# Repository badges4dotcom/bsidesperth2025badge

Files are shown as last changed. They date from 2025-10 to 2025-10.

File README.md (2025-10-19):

# BSides Perth 2025 Badge

## Physical Badge

Instructions on how to assemble the physical badge can be found [here](docs/AssemblyInstructions.md)

If a re-download of the physical badge is required, follow these [instructions](docs/DownloadInstructions.md). This will be required if you wish to attempt the online challenges (see Known Issues below).

### Parts List

| Qty | Item | Link | Alternative Link |
| --- | --- | --- | --- |
| 4	| 6x6x6mm Push Button Tactile Switch | [Link](https://a.aliexpress.com/_mtKEuoZ) || 
| 4	| 10k 1/4W 1% Metal Film Resistor | [Link](https://a.aliexpress.com/_m0tmaNF) ||
| 1	| 1x4 2.54mm Male Header Pin Connector | [Link](https://a.aliexpress.com/_mLn1ap7) ||
| 1	| 1x8 2.54mm Female Header Pin Connector | [Link](https://a.aliexpress.com/_mquvebf) | [Link](https://a.aliexpress.com/_mNltGYh) |
| 1	| 1x4 2.54mm Female Header Pin Connector | [Link](https://a.aliexpress.com/_mquvebf) | [Link](https://a.aliexpress.com/_mNltGYh) |
| 2	| 1x15 2.54mm Female Header Pin Connector | [Link](https://a.aliexpress.com/_mquvebf) | [Link](https://a.aliexpress.com/_mNltGYh) |
| 1	| 2x3 2.54mm Femal Header Pin Connector	| [Link](https://a.aliexpress.com/_mK6bxvJ) ||
| 1	| ESP32 DOIT DevKit v1 - 30Pin | [Link](https://a.aliexpress.com/_mr7LSPJ) ||
| 1	| 1.8" LCD TFT Display | [Link](https://a.aliexpress.com/_mPspKyp) ||

## Virtual Badge

The virtual badge can be accessed here: https://badge.bsidesperth.com.au/

The code for the Virtual Badge code can be found in this repository under "VirtualBadge".

The virtual badge does not support "Online Challenges", but does contain hidden features such as a second episode, cheats, and an easter egg.

The virtual badge now supports keyboard inputs. The four buttons are mapped to W [Up], S [Down], A [Left/A], and D [Right/B]. Once a keyboard input is used, the symbols used in the sequence game change to U = UP, D = DOWN, L = LEFT, R = RIGHT. Thanks again to Matt for the suggestion and the code snippet for this feature. 

## Physical Badge Code Template

There is a basic template for an Arduino program under the folder "Template". The template demonstrates basic use of the LCD screen, ESP32, and button inputs. The download instructions can be found [here](docs/DownloadInstructions.md).

## Virtual Badge Server (API for Online Challenges)

Code for the Virtual Badge Server (API for Online Challenges) will be made available ~1st November 2025.

## Badge Holder (3D Print)

A badge holder can be 3D printed using an off-the-shelf 3D printer. Recommended print settings are PLA plastic, 60+% infill, 40mm/s print speed. Some stringing may occur if filament is damp and/or print speed is too high.

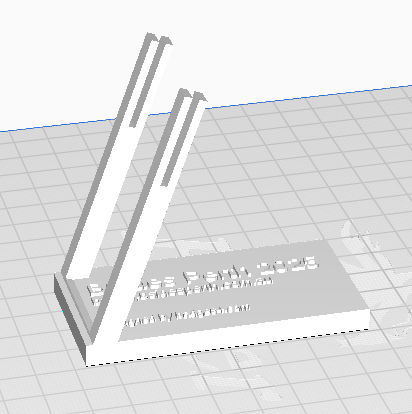
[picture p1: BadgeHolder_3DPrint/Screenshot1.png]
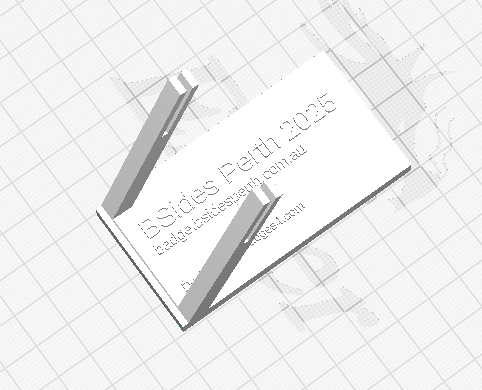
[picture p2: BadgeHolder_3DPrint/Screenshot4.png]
 

## Customisation

Customisation of the virtual and physical badge are both possible. Extra details can be found [here](docs/Customisation.md)

## Known Issues

- To play the Online Challenges on a ESP32 supplied in a component pack, a re-download of the physical badge code to the ESP32 is required. [Fixed]
- Online Challenges were unavailable (18th Oct) due to firewall issue. This has since been resolved. [Fixed]
- Offline Challenges now generates sequences which use all four buttons (only three buttons were being used in the original code). [Fixed]

## Like the game/badge?

"Buy Me A Coffee" (https://buymeacoffee.com/badges4dotcom)

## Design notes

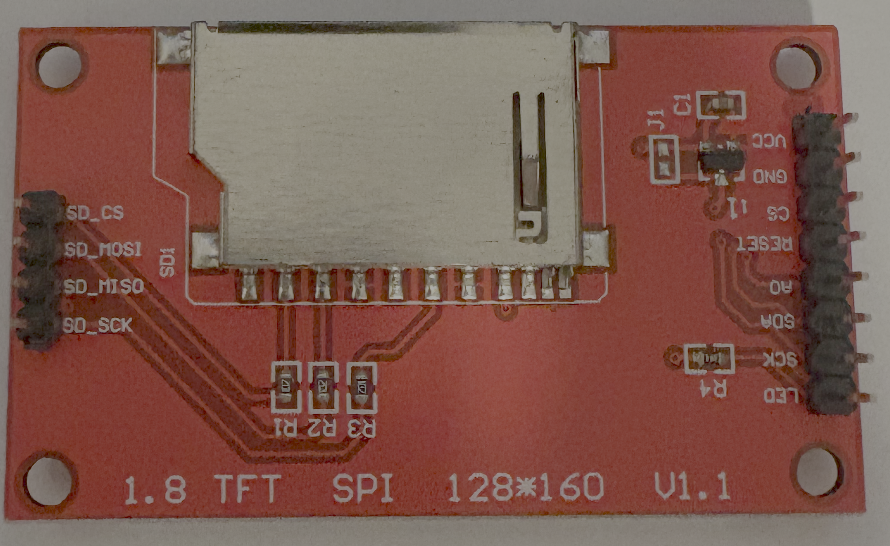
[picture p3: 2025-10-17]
docs/Images/LCD.png

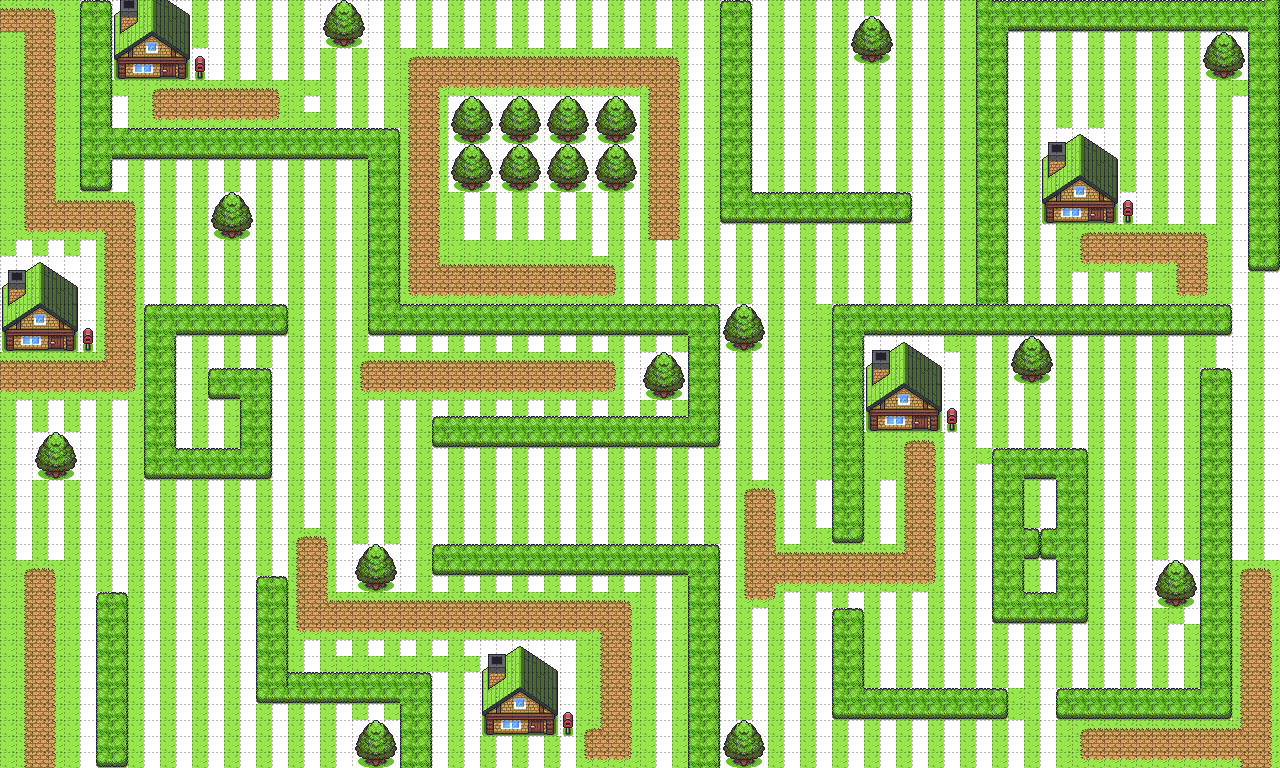
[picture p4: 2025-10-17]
GameMap/Exports/Episode1Map.png

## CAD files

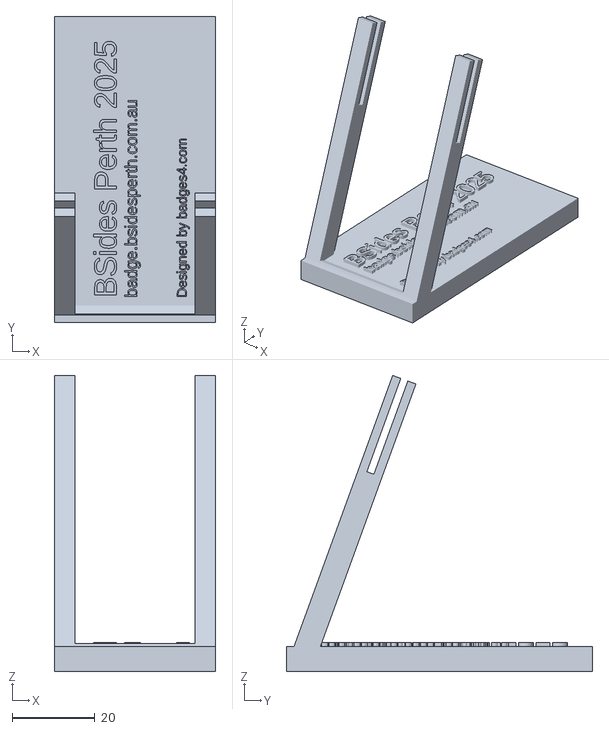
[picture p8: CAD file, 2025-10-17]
BadgeHolder_3DPrint/BadgeHolder.stl
39.0 x 74.0 x 71.6

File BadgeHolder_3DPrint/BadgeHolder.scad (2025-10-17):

union() {
    translate([0, 6, 0]) rotate([70,0,0]) {
        difference() {
            union() {
                cube([5, 74, 6]);
                cube([39, 5, 6]);
                translate([34, 0, 0]) cube([5, 74, 6]);
            }
            translate([-1,50,2.1]) cube([41, 25, 1.8]);
        }
    }
    cube([39, 74, 6]);
}

translate([15, 6, 6]) rotate([0, 0, 90]) linear_extrude(1) text("BSides Perth 2025", 5.5);
translate([20, 6, 6]) rotate([0, 0, 90]) linear_extrude(1) text("badge.bsidesperth.com.au", 3);
translate([32, 6, 6]) rotate([0, 0, 90]) linear_extrude(1) text("Designed by badges4.com", 2.4);

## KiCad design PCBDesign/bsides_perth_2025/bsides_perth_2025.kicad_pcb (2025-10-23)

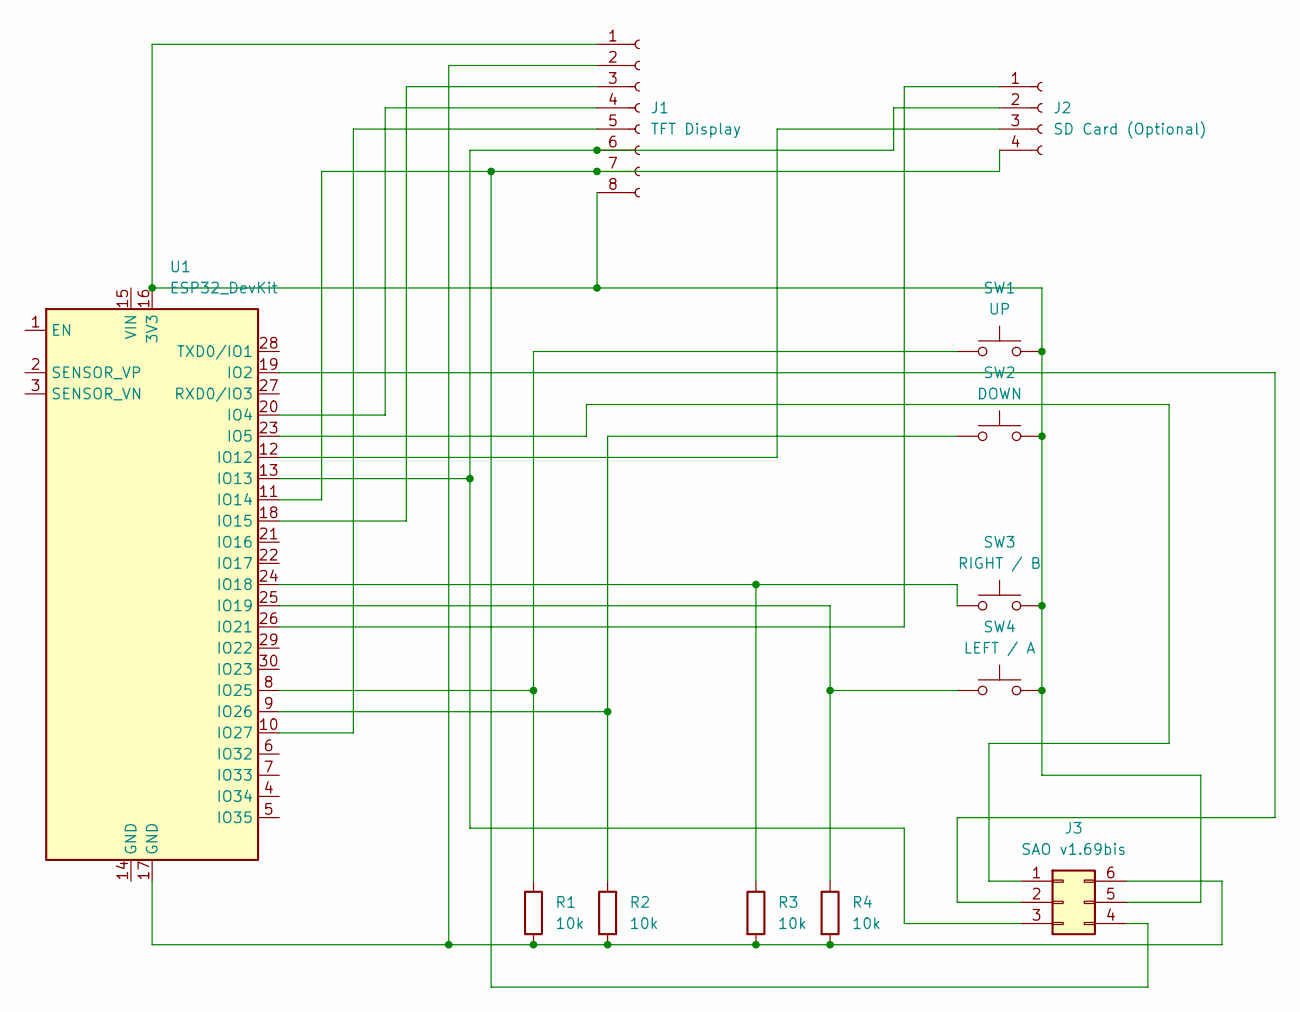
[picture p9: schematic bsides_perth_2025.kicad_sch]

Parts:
J1: TFT Display; PinHeader_1x08_P2.54mm_Vertical
J2: SD Card (Optional); PinHeader_1x04_P2.54mm_Vertical
J3: SAO v1.69bis; PinHeader_2x03_P2.54mm_Vertical
R1, R2, R3, R4: 10k; R_Axial_DIN0207_L6.3mm_D2.5mm_P10.16mm_Horizontal
SW1: UP; SW_PUSH_6mm_H5mm
SW2: DOWN; SW_PUSH_6mm_H5mm
SW3: RIGHT / B; SW_PUSH_6mm_H5mm
SW4: LEFT / A; SW_PUSH_6mm_H5mm
U1: ESP32_DevKit; esp32_devkit_v1_doit

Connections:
unnamed: J1.1, J1.8, J3.5, SW1.2, SW2.2, SW3.2, SW4.2, U1.16 (3V3)
unnamed: J1.2, J3.6, R1.2, R2.2, R3.2, R4.2, U1.17 (GND)
unnamed: J1.3, U1.18 (IO15)
unnamed: J1.4, U1.20 (IO4)
unnamed: J1.5, U1.10 (IO27)
unnamed: J1.6, J2.2, J3.3, U1.13 (IO13)
unnamed: J1.7, J2.4, J3.4, U1.11 (IO14)
unnamed: J2.1, U1.26 (IO21)
unnamed: J2.3, U1.12 (IO12)
unnamed: J3.1, U1.23 (IO5)
unnamed: J3.2, U1.19 (IO2)
unnamed: R1.1, SW1.1, U1.8 (IO25)
unnamed: R2.1, SW2.1, U1.9 (IO26)
unnamed: R3.1, SW3.1, U1.24 (IO18)
unnamed: R4.1, SW4.1, U1.25 (IO19)

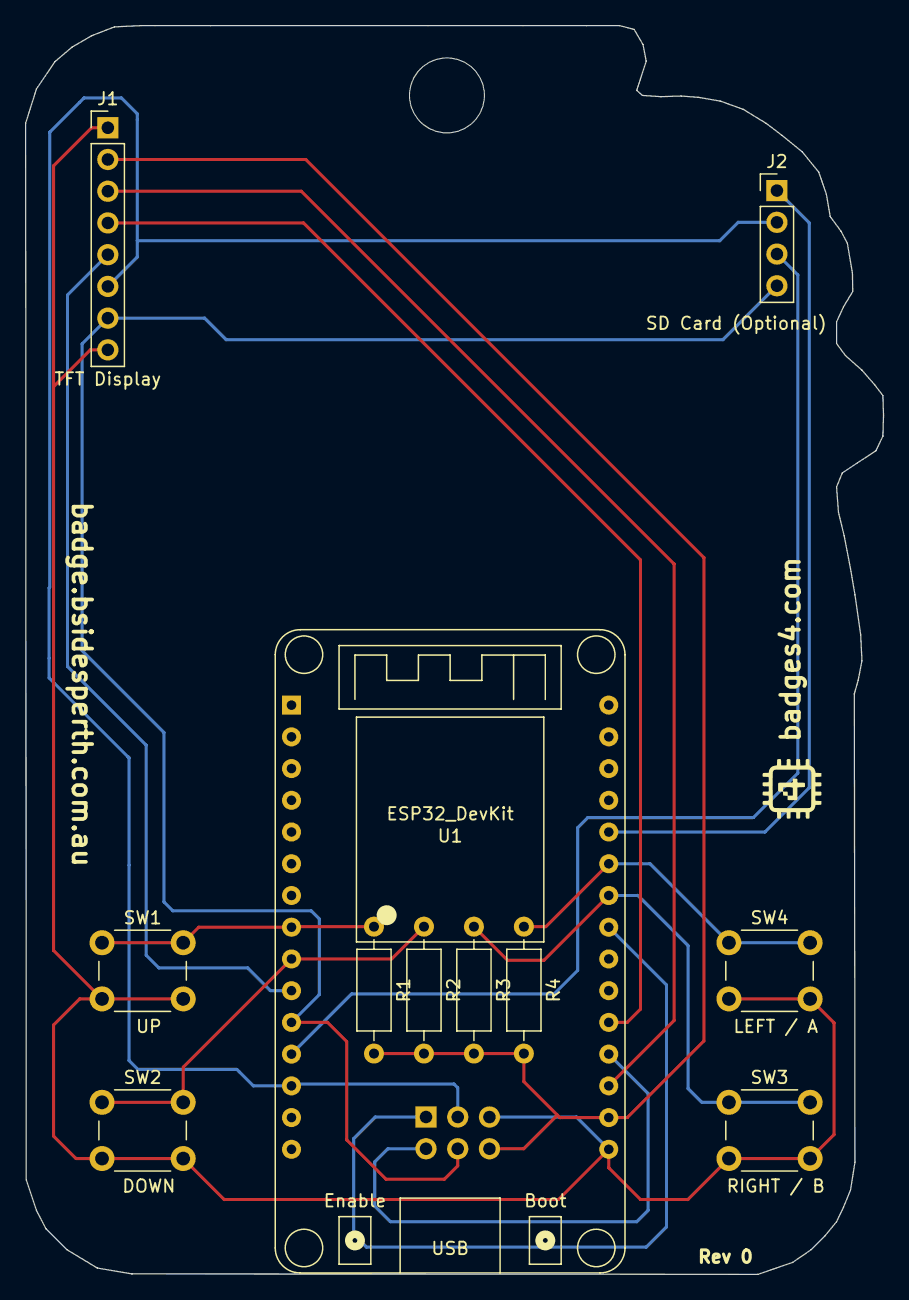
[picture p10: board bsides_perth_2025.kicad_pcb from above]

Board: 2 copper layers, 68.7 x 100.0 mm, 12 parts (1 on the bottom side), 15 nets.

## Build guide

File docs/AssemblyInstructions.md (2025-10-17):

# BSides Perth 2025 Badge

## Physical Badge Assembly Instructions

The completed badge should look like this, abeit a different colour, (minus the ESP32 and LCD):

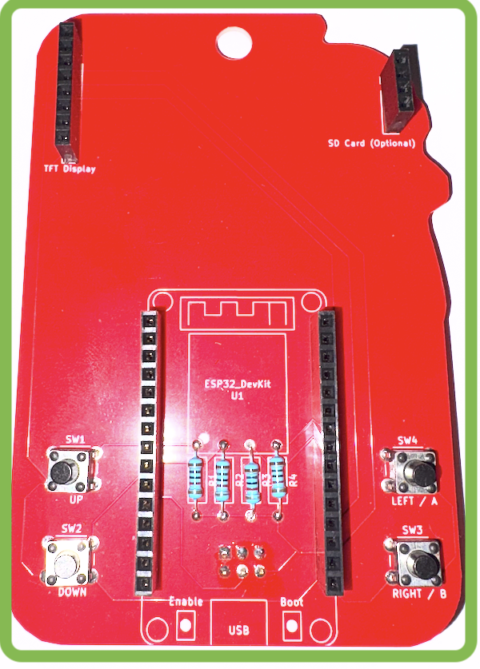
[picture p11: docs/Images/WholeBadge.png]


If unsure on any of these instructions, please consult a BSides Perth team member at the assembly stations before soldering.

1. Place the four resistors into the board, bend resistor legs to prevent resistors from falling out. Turn over and solder.

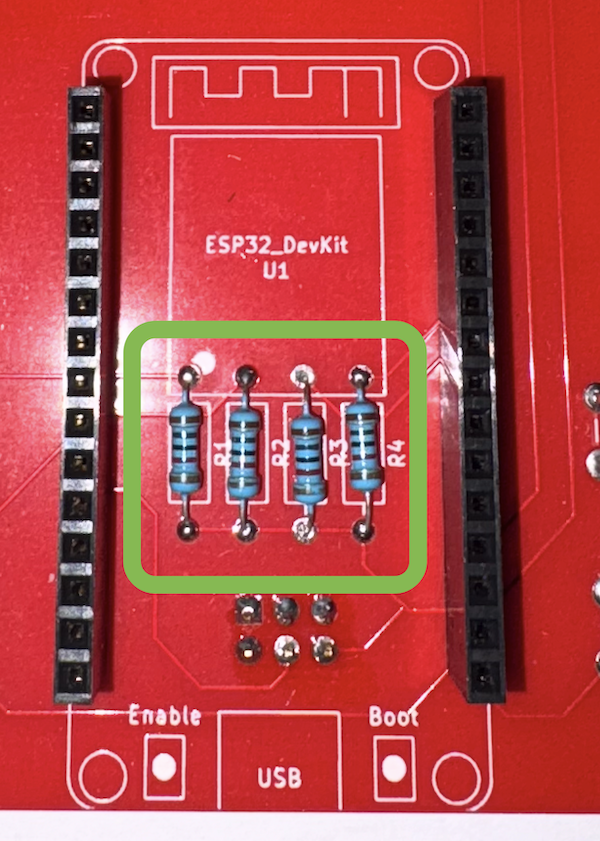
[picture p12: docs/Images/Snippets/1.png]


2. Once resistors are soldered, trim resistor legs with a pair of side-cutters.
3. Insert the two 1x15 pin headers into the board, hold in place, and turn over the board. Solder the 30 pins in place.

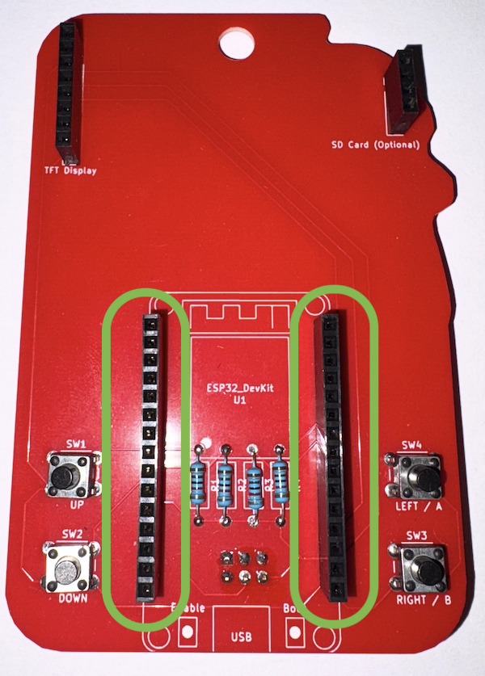
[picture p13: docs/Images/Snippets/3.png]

4. Insert the four buttons into the board; ensure the legs clip into the board horizontally*. Turn over and solder in place.

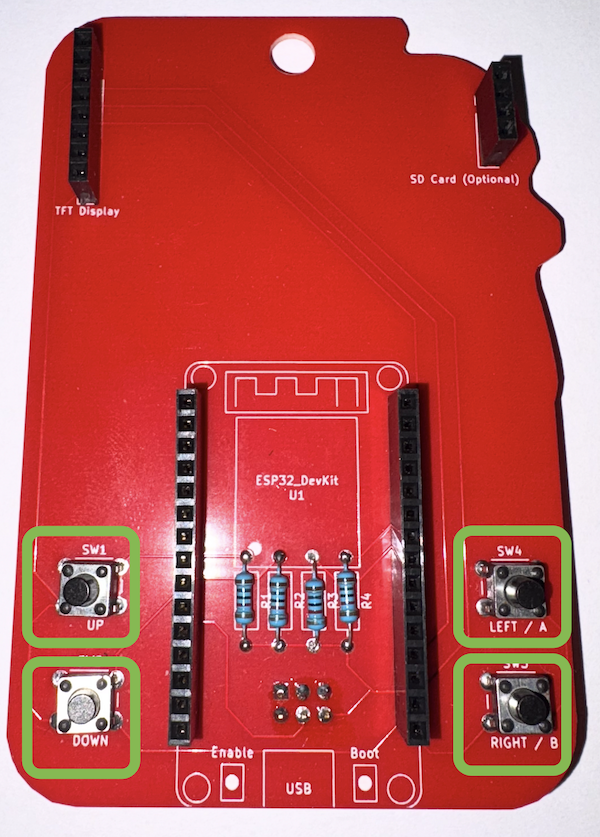
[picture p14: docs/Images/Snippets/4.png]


5. Insert the 1x8 and 1x4 pin headers into the board, hold in place, and turn over the board. Solder the 12 pins in place.

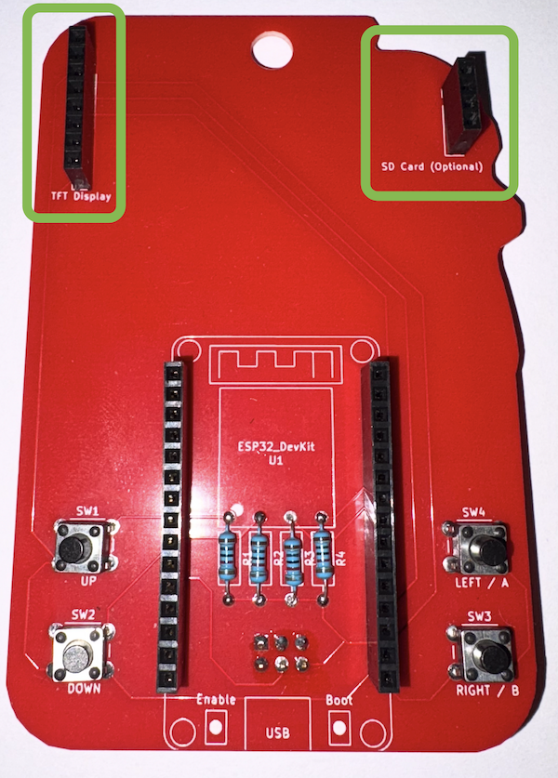
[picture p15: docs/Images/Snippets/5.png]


6. [Optional] Insert 2x3 pin header into the opposite side of the board, and solder the 6 pins in place.

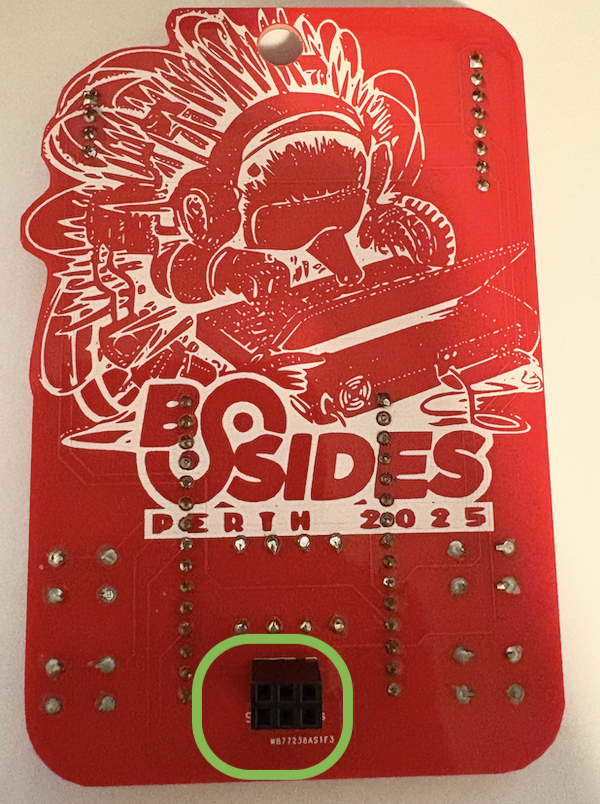
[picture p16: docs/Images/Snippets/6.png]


7. Place the 1x4 pin male header into the LCD screen, ensuring the longer pins are furthest away from the LCD board, turn over LCD board, and solder the 4 pins in place. 

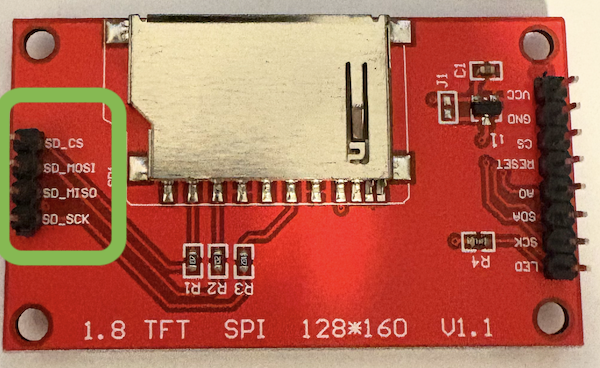
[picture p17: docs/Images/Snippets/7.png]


8. Insert the ESP32 and LCD into the respective header pins.
9. Insert micro-USB cable and power on the badge.

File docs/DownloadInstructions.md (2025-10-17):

# BSides Perth 2025 Badge

## Physical Badge Download Instructions

To download the code to the physical badge, perform the following:
1. Download and install Arduino IDE from [https://www.arduino.cc/en/software/](https://www.arduino.cc/en/software/)
2. Open Arduino IDE
3. In the menu, navigate to File>Open... , and select the project folder.
4. In the drop down box at the top of the window, select "Select other board and port..."
5. Select "DOIT ESP32 DEVKIT V1". If it is not available, follow "Install ESP32 Boards" instructions below.
6. On the left of the window, click the books icon (Library Manager).
7. Install the following libraries: SD, Adafruit BusIO, Adafruit GFX Library, Adafruit ST7735 and ST7789 Library, ArduinoJson, and RLEBitmap.
8. Plug in ESP32 into USB port.
9. In the menu, select Tools > Port, and select the port corresponding with the USB Serial / ESP32.
10. In the menu, select Sketch > Upload
11. Upload should take about 1-5mins.

## Install ESP32 Boards

1. In the Arduino window, select the "Boards Manager" item/icon on the left hand side.
2. Search for ESP32 in the search bar at the top.
3. Click on the "Install" button under "esp32 by Espressif""

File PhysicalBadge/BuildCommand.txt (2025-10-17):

"/Users/tim/Library/Arduino15/packages/esp32/tools/esptool_py/5.0.dev1/esptool" --chip esp32 --port "/dev/cu.usbserial-2” --baud 921600  --before default-reset --after hard-reset write-flash -e -z --flash-mode keep --flash-freq keep --flash-size keep 0x1000 "/Users/tim/Desktop/BadgeProgrammer/build/esp32.esp32.esp32doit-devkit-v1/BSides.ino.bootloader.bin" 0x8000 "/Users/tim/Desktop/BadgeProgrammer/build/esp32.esp32.esp32doit-devkit-v1/BSides.ino.partitions.bin" 0xe000 "/Users/tim/Library/Arduino15/packages/esp32/hardware/esp32/3.2.1/tools/partitions/boot_app0.bin" 0x10000 "/Users/tim/Desktop/BadgeProgrammer/build/esp32.esp32.esp32doit-devkit-v1/BSides.ino.bin"

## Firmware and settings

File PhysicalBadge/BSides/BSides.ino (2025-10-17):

#include <Adafruit_GFX.h>
#include <Adafruit_ST7735.h>
#include <ArduinoJson.h>
#include <EEPROM.h>
#include <SD.h>
#include <SPI.h>
#include <WiFi.h>
#include <WiFiClientSecure.h>

#include <RLEBitmap.h>

#include "images/Badges4_Icon_Small.h"
#include "images/BlueWren.h"
#include "images/BSides_Perth_2025_Logo.h"
#include "images/Cockatoo.h"
#include "images/Computer.h"
#include "images/Crow.h"
#include "images/Cross.h"
#include "images/CyberEchidna.h"
#include "images/Devil.h"
#include "images/Dingo.h"
#include "images/Echidna.h"
#include "images/Emu.h"
#include "images/Explosion.h"
#include "images/Kangaroo.h"
#include "images/Kookaburra.h"
#include "images/Koala.h"
#include "images/Lightning.h"
#include "images/Parrot.h"
#include "images/Person.h"
#include "images/Person2.h"
#include "images/Person3.h"
#include "images/Person4.h"
#include "images/Person5.h"
#include "images/Person6.h"
#include "images/Person7.h"
#include "images/Snake.h"
#include "images/Spider.h"
#include "images/Tick.h"
#include "images/Tilemap_NonRLE.h"
#include "images/Warning.h"
#include "images/WiFi.h"
#include "images/Wombat.h"

#include "Game_Data.h"

String mainMenuItems[] = {"Start","Status","Wi-Fi", "Reset"};
int mainMenuItemsCount = 4;

SPIClass tftHSPI = SPIClass(HSPI);
Adafruit_ST7735 tft = Adafruit_ST7735(&tftHSPI, TFT_CS, TFT_DC, TFT_RST);

unsigned long lastDebounceTime = 0;
unsigned long debounceDelay = 50;
int lastKeyRegister = 0;

bool bGameRunning;
UserSettings user;
bool redrawWholeMap;
bool playGameCompletionAnimation;

// Displays the first screen with the BSides Perth Logo.
void displayHomeScreen() {
	initialiseScreenAndText();
  displayImage("Logo", (int16_t)((SCREEN_WIDTH - 96) / 2), 0, 1);

  tft.setCursor(42, 120);
  tft.print("Press any key.");
}

// Displays the badges4 logo.
void displayBadges4Logo() {
	initialiseScreenAndText();
  tft.drawRGBBitmap(64,32,Badges4_Icon_Small,33,32);

  tft.setTextSize(2);
  tft.setTextColor(0xef5d);
  tft.setCursor(16, 70);
  tft.print("badges4.com");

  tft.setTextSize(1);
  tft.setTextColor(ST77XX_WHITE);

  tft.setCursor(42, 120);
  tft.print("Press any key.");  
}

// Sets up the program.
void setup(void) {
  randomSeed(analogRead(0));

  pinMode(UP_KEY_INPUT, INPUT);
  pinMode(DOWN_KEY_INPUT, INPUT);  
  pinMode(A_KEY_INPUT, INPUT);
  pinMode(B_KEY_INPUT, INPUT);
  pinMode(available_gpio[GPIO_CHALLENGE_PTR], INPUT);   // Enable the additional input for GP Gertrude challenge.
  
  tftHSPI.begin();
  tft.initR(INITR_BLACKTAB);
  tft.setSPISpeed(20000000);
  tft.setRotation(3);

  tft.fillScreen(ST77XX_BLACK);
  tft.setCursor(0, 0);

  EEPROM.begin(128);
  readUserSettings();

  displayHomeScreen();
  blockForKeyPress();

  displayBadges4Logo();
  blockForKeyPress();
  blockForKeyPress();

  tft.fillScreen(ST77XX_BLACK);
  runMenuLoop();
}

// Main loop for the menu.
void runMenuLoop() {
  int keyPress;
  int menuItem;

  menuItem = 0;
  while (true) {
    keyPress = 0; // Probably not needed.
    displayMenu(mainMenuItems, mainMenuItemsCount, menuItem, MAX_MENUITEMS_ONSCREEN, 2);
    keyPress = blockForKeyPress();

    if ((keyPress&DOWN_KEY_REGISTER)>0) menuItem++;
    if ((keyPress&UP_KEY_REGISTER)>0) menuItem--;

    // Check to see if its still in bounds.
    if (menuItem > (mainMenuItemsCount-1)) menuItem = mainMenuItemsCount-1;
    if (menuItem < 0) menuItem = 0;

    if ((keyPress&A_KEY_REGISTER)>0) {
      switch (menuItem) {
        case 0:
          if (getNumberOfAnimalsCollected()==0) startIntro(); // If no animals have been collected, do intro.
          runGameLoop();
          break;
        case 1:
          displayStatusOneScreen();
          keyPress = blockForKeyPress();
          keyPress = blockForKeyPress();
          displayStatusTwoScreen();
          keyPress = blockForKeyPress();
          keyPress = blockForKeyPress();
          displayStatusThreeScreen();
          keyPress = blockForKeyPress();
          keyPress = blockForKeyPress();
          break;
        case 2:
          configureWiFi();
          break;
        case 3:
          initialiseUserSettings(true);
          break;
      }
    }
  }
}

// Main game loop.
void runGameLoop() {
  bGameRunning = true;
  redrawWholeMap = true;
  playGameCompletionAnimation = false;

  relocateAnimalsToTheirLocations();
  while (bGameRunning) {
    checkForGameCompletion();

    drawGameMap();
    drawAnimals();
    drawBSidesBenny();
    drawCharacter();

    resetDrawWholeMap();

    checkForMovement();
    checkForInteraction();
  }
}

// I don't know why I didn't use the Arduino loop function ¯\_(ツ)_/¯.
void loop() {
}

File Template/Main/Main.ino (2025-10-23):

#include <Adafruit_GFX.h>
#include <Adafruit_ST7735.h>
#include <SPI.h>
#include <WiFi.h>

#include "Definitions.h"

SPIClass tftHSPI = SPIClass(HSPI);
Adafruit_ST7735 tft = Adafruit_ST7735(&tftHSPI, TFT_CS, TFT_DC, TFT_RST);

unsigned long lastDebounceTime = 0;
unsigned long debounceDelay = 50;
int lastKeyRegister = 0;

// Sets up the program.
void setup(void) {
  pinMode(UP_KEY_INPUT, INPUT);
  pinMode(DOWN_KEY_INPUT, INPUT);  
  pinMode(A_KEY_INPUT, INPUT);
  pinMode(B_KEY_INPUT, INPUT);
  
  tftHSPI.begin();
  tft.initR(INITR_BLACKTAB);
  tft.setSPISpeed(20000000);
  tft.setRotation(3);

  tft.fillScreen(ST77XX_BLACK);
  tft.setCursor(0, 0);

  // Connect to WiFi
  /*
  configureWiFi();
  connectToWiFi("BSidesWiFi","DoesThisWiFiAPEvenExist?");   // Not a real AP. Returns True if the connection is successful, False otherwise.
  */
}

void loop() {
  displayTextDisplay();
  displaySpirals();
}

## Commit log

2025-10-17 Badge Holder - 3D Print
    Including the 3D Print for the Badge Holder
    [BadgeHolder.scad, BadgeHolder.stl]
2025-10-17 Updated Assembly Instructions
2025-10-18 Added parts list and minor fix
    Added parts list
    Improved Offline Challenge to use all four buttons for sequence
    [Challenge.ino]
2025-10-19 Minor fixes, and keyboard support
    Minor fixes
    Keyboard Support
    [AllJavaScript.js]
2025-10-20 Moved arduino project into directory named BSides so arduino ide does not complain
2025-10-20 Add github action to build binary for ESP32
2025-10-23 Badge Software Template + PCB Design
    Addition of:
    1) Badge Software Template
    2) PCB Design
    [bsides_perth_2025.kicad_pcb, bsides_perth_2025.kicad_sch]
